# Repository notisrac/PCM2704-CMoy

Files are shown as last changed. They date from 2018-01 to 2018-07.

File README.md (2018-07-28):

# PCM2704-CMoy
[CMoy](https://tangentsoft.net/audio/cmoy/) headphone amp with a [PCM2704](http://www.ti.com/product/PCM2704) DAC

# Technical highlights
* Charge-pump power supply (instead of rail splitter)
* Runs off a 18V wallwart power supply
* The DAC is self powered

## Acknowledgements
[http://www.pavouk.org/hw/usbdacpcm2704/en_index.html](http://www.pavouk.org/hw/usbdacpcm2704/en_index.html)
[http://www.isendev.com/app/entry/12](http://www.isendev.com/app/entry/12)

Analytics (https://github.com/igrigorik/ga-beacon)

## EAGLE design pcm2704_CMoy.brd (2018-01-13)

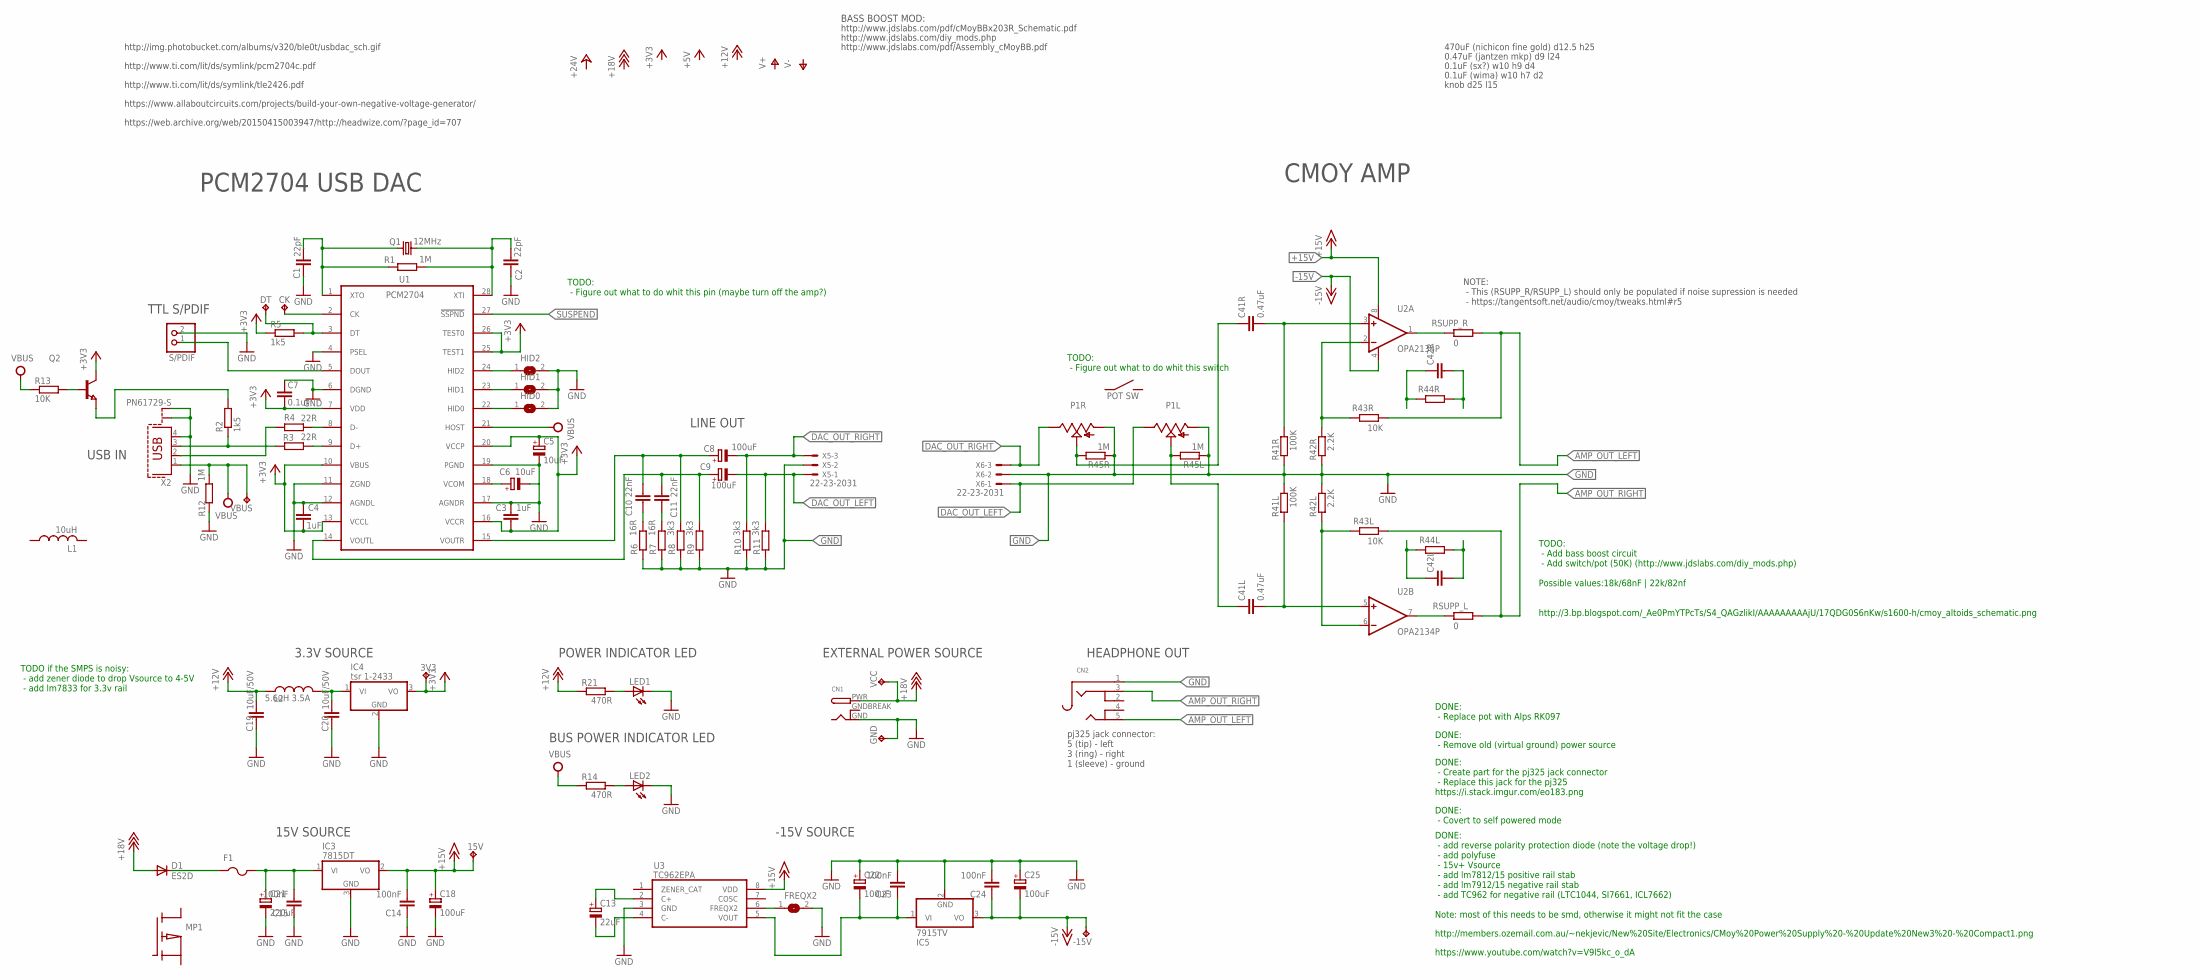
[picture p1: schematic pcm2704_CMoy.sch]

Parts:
3V3, 15V: TPTP20R; TP20R
-15V: TPTP20R; TP20R
C1, C2: 22pF; C0805
C3, C4: 1uF; C0805
C5, C6: 10uF; E2,5-7
C7: 0.1uF; C0805
C8, C9: 100uF; E3,5-10
C10, C11: 22nF; C050-025X075
C13: 22uF; E2,5-7
C14, C15, C23, C24: 100nF; C1206
C18, C22, C25: 100uF; E2,5-7
C19, C20: 10uF/50V; C1206
C21: 220uF; E2,5-7
C41L, C41R: 0.47uF; C27.5B11
C42L, C42R: C7.5/4; C7.5B4
CK: TPTP20R; TP20R
CN1: DCBARRELPTH; DCJACK_2MM_PTH
CN2: AUDIO_3.5MMJACKPTH; 4UCONN_05550
D1: ES2D; SMB
DT: TPTP20R; TP20R
F1: PTCFUSE-1812; 1812
FREQX2: SJ
GND: TPTP20R; TP20R
HID0, HID1, HID2: SJ
IC3: 7815DT; TO252
IC4: tsr 1-2433; TO220V
IC5: 7915TV; TO220V
L1: 10uH; L1812
L2: 5.6uH 3.5A; L1812
LED1, LED2: LED3MM
MP1: PMOS; SOT23
P1: ALPS_RK0971221Z0N; ALPS_RK0971221Z0X
Q1: 12MHz; HC49/S
Q2: NPN-TRANSISTOR_SOT23; SOT23
R1, R12: 1M; M0805
R2, R5: 1k5; R0805
R3, R4: 22R; R0805
R6, R7: 16R; 0204/7
R8, R9, R10, R11: 3k3; 0204/7
R13: 10K; R0805
R14, R21: 470R; 0204/7
R41L, R41R: 100K; 0204/7
R42L, R42R: 2.2K; 0204/7
R43L, R43R: 10K; 0204/7
R44L, R44R: R-EU_0204/7; 0204/7
R45L, R45R: 1M; 0204/7
RSUPP_L: 0; 0204/7
RSUPP_R: 0; 0204/7
S/PDIF: PINHD-1X2; 1X02
U1: PCM2704; SSOP28DB
U2: OPA2134P; DIL08
U3: TC962EPA; PDIP8_300MC
VBUS: TPTP20R; TP20R
VCC: TPTP20R; TP20R
X2: PN61729-S
X5, X6: 22-23-2031

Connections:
+3V3: 3V3.TP, C3.1, C4.2, C5.+, C7.2, IC4.3 (VO), Q2.3 (C), R5.1, U1.7 (VDD), U1.10 (VBUS), U1.13 (VCCL), U1.16 (VCCR), U1.20 (VCCP), U1.25 (TEST1), U1.26 (TEST0)
+12V: C19.2, L2.1, R21.1
+15V: 15V.TP, C14.2, C18.+, IC3.2 (VO), U2.8 (V+), U3.8 (VDD)
+18V: CN1.PWR, D1.A, VCC.TP
-15V: -15V.TP, C24.1, C25.-, IC5.3 (VO), U2.4 (V-)
AMP_OUT_LEFT: CN2.5, R43R.1, RSUPP_R.1
AMP_OUT_RIGHT: CN2.3, R43L.1, RSUPP_L.1
DAC_OUT_LEFT: C9.-, P1.I1 (3), R11.2, X5.1, X6.1
DAC_OUT_RIGHT: C8.-, P1.I2 (3), R10.2, X5.3, X6.3
GND: C1.2, C2.2, C3.2, C4.1, C5.-, C6.-, C7.1, C14.1, C15.1, C18.-, C19.1, C20.1, C21.-, C22.+, C23.2, C24.2, C25.+, CN1.GND, CN2.1, FREQX2.2, GND.TP, HID0.2, HID1.2, HID2.2, IC3.3 (GND), IC4.2 (GND), IC5.2 (GND), LED1.K (C), LED2.K (C), P1.G1 (1), P1.G2 (1), R6.1, R7.1, R8.1, R9.1, R10.1, R11.1, R12.1, R41L.2, R41R.1, R42L.2, R42R.1, R45L.1, R45R.1, S/PDIF.2, U1.4 (PSEL), U1.6 (DGND), U1.11 (ZGND), U1.12 (AGNDL), U1.17 (AGNDR), U1.19 (PGND), U3.3 (GND), X2.4, X2.S1, X2.S2, X5.2, X6.2
GNDBREAK: CN1.GNDBREAK
unnamed: D1.C, F1.1
unnamed: LED2.A, R14.2
unnamed: R4.1, X2.2
unnamed: R4.2, U1.8 (D-)
unnamed: R2.1, R3.1, X2.3
unnamed: R3.2, U1.9 (D+)
unnamed: C20.2, IC4.1 (VI), L2.2
unnamed: LED1.A, R21.2
unnamed: CK.TP, U1.2 (CK)
unnamed: C1.1, Q1.1, R1.1, U1.1 (XTO)
unnamed: C2.1, Q1.2, R1.2, U1.28 (XTI)
unnamed: HID2.1, U1.24 (HID2)
unnamed: C42L.2, R44L.1
unnamed: C42L.1, R44L.2
unnamed: HID1.1, U1.23 (HID1)
unnamed: HID0.1, U1.22 (HID0)
unnamed: C41L.2, R41L.1, U2.5 (+IN)
unnamed: C41R.2, R41R.2, U2.3 (+IN)
unnamed: C41R.1, P1.O2 (2), R45R.2
unnamed: DT.TP, R5.2, U1.3 (DT)
unnamed: C41L.1, P1.O1 (2), R45L.2
unnamed: R42R.2, R43R.2, U2.2 (-IN)
unnamed: R42L.1, R43L.2, U2.6 (-IN)
unnamed: C15.2, C21.+, F1.2, IC3.1 (VI)
unnamed: FREQX2.1, U3.6 (FREQX2)
unnamed: C10.2, R6.2
unnamed: C11.2, R7.2
unnamed: C8.+, C10.1, R8.2, U1.15 (VOUTR)
unnamed: C9.+, C11.1, R9.2, U1.14 (VOUTL)
unnamed: C13.+, U3.2 (C+)
unnamed: C13.-, U3.4 (C-)
unnamed: S/PDIF.1, U1.5 (DOUT)
unnamed: RSUPP_R.2, U2.1 (OUT)
unnamed: C22.-, C23.1, IC5.1 (VI), U3.5 (VOUT)
unnamed: RSUPP_L.2, U2.7 (OUT)
unnamed: C42R.1, R44R.2
unnamed: C42R.2, R44R.1
unnamed: Q2.1 (B), R13.2
unnamed: Q2.2 (E), R2.2
S1: P1.S1
S2: P1.S2
SUSPEND: U1.27 (!SSPND)
VBUS: R12.2, R13.1, R14.1, U1.21 (HOST), VBUS.TP, X2.1
VCOM: C6.+, U1.18 (VCOM)

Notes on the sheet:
LINE OUT
USB IN
PCM2704 USB DAC
TTL S/PDIF
470uF (nichicon fine gold) d12.5 h25
0.47uF (jantzen mkp) d9 l24
0.1uF (sx?) w10 h9 d4
0.1uF (wima) w10 h7 d2
knob d25 l15
http://img.photobucket.com/albums/v320/ble0t/usbdac_sch.gif
http://www.ti.com/lit/ds/symlink/pcm2704c.pdf
3.3V SOURCE
POWER INDICATOR LED
CMOY AMP
EXTERNAL POWER SOURCE
HEADPHONE OUT
http://www.ti.com/lit/ds/symlink/tle2426.pdf
https://www.allaboutcircuits.com/projects/build-your-own-negative-voltage-generator/
http://www.jdslabs.com/pdf/cMoyBBx203R_Schematic.pdf
http://www.jdslabs.com/diy_mods.php
http://www.jdslabs.com/pdf/Assembly_cMoyBB.pdf
BASS BOOST MOD:
http://members.ozemail.com.au/~nekjevic/New%20Site/Electronics/CMoy%20Power%20Supply%20-%20Update%20New3%20-%20Compact1.png
DONE: - add reverse polarity protection diode (note the voltage drop!) - add polyfuse - 15v+ Vsource - add lm7812/15 positive rail stab - add lm7912/15 negative rail stab - add TC962 for negative rail (LTC1044, SI7661, ICL7662) Note: most of this needs to be smd, otherwise it might not fit the case
DONE: - Covert to self powered mode
DONE: - Remove old (virtual ground) power source
DONE: - Replace pot with Alps RK097
TODO: - Add bass boost circuit - Add switch/pot (50K) (http://www.jdslabs.com/diy_mods.php) Possible values:18k/68nF | 22k/82nf http://3.bp.blogspot.com/_Ae0PmYTPcTs/S4_QAGzlikI/AAAAAAAAAjU/17QDG0S6nKw/s1600-h/cmoy_altoids_schematic.png
https://www.youtube.com/watch?v=V9l5kc_o_dA
https://web.archive.org/web/20150415003947/http://headwize.com/?page_id=707
NOTE: - This (RSUPP_R/RSUPP_L) should only be populated if noise supression is needed - https://tangentsoft.net/audio/cmoy/tweaks.html#r5
DONE: - Create part for the pj325 jack connector - Replace this jack for the pj325 https://i.stack.imgur.com/eo183.png
TODO: - Figure out what to do whit this pin (maybe turn off the amp?)
15V SOURCE
-15V SOURCE
TODO: - Figure out what to do whit this switch
pj325 jack connector: 5 (tip) - left 3 (ring) - right 1 (sleeve) - ground
TODO if the SMPS is noisy: - add zener diode to drop Vsource to 4-5V - add lm7833 for 3.3v rail
BUS POWER INDICATOR LED

Board: 2 copper layers, 87 parts (0 on the bottom side), 51 nets, no tracks yet.

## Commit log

2018-01-02 - Replaced current pot with Alps RK097
    - Removed old (virtual ground) power source
    - Added reverse polarity protection diode - still needs work (should it be a mosfet?)
    - Added polyfuse
    - Added +15V rail
    - Added -15V rail (TC962)
    [pcm2704_CMoy.brd, pcm2704_CMoy.sch]
2018-01-06 Minor component placement changes
    [pcm2704_CMoy.brd, pcm2704_CMoy.sch]
2018-01-06 - Replaced the audio jack with a PF325
    - Renamed the resistors and the capacitors in the amp to reflect the side they are used on (R/L)
    [pcm2704_CMoy.brd, pcm2704_CMoy.sch]
2018-01-09 - Modified PCM2704 to be self powered
    - Modified the resistor names of the dac to match the example schematic in the datasheet
    [pcm2704_CMoy.brd, pcm2704_CMoy.sch]
2018-01-09 - Added D+ pullup activator transistor
    [pcm2704_CMoy.brd, pcm2704_CMoy.sch]
2018-01-10 - Modified capacitor names to match the datasheet example (DAC)
    - Fixed a few capacitor values that did not match the datasheet example (DAC)
    [pcm2704_CMoy.brd, pcm2704_CMoy.sch]
2018-01-10 - Removed the external rom connector, because it does not support descriptor overwriting in self powered mode
    [pcm2704_CMoy.brd, pcm2704_CMoy.sch]
2018-01-10 - Cosmetics
    - Added bus power indicator led
    [pcm2704_CMoy.brd, pcm2704_CMoy.sch]
2018-01-13 - Added resistor between the wiper and ground of the volume pot
    - Fixed the pot direction
    [pcm2704_CMoy.brd, pcm2704_CMoy.sch]

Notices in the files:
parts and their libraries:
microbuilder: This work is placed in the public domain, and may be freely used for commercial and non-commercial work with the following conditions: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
